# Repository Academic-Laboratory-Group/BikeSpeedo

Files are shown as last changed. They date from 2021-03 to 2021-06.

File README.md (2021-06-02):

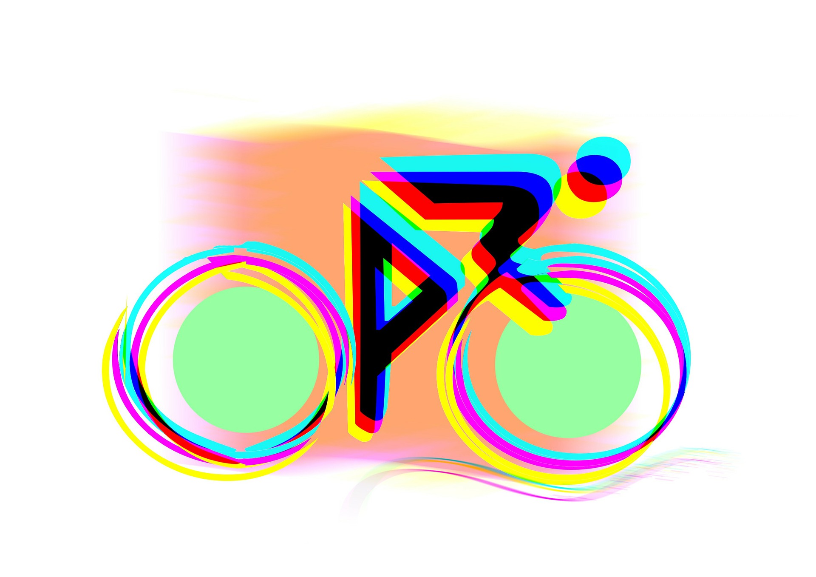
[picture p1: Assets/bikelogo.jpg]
ReadMe


# BikeSpeedo
Bicycle speedometer. Project for Sensors In Embedded Systems, Electronics and Telecommunications, master's studies at University of Science and Technology in Cracow. Classes are led in Polish so description and files from this place will be too, except code and other source files.

## Cel projektu
Celem projektu jest skonstruowanie modułu prędkościomierza rowerowego do płytki Nucleo. Należy zaprojektować płytkę PCB oraz oprogramowanie. Ważną cechą projektu ma być przystępna cena gotowego produktu mimo zainstalowanych w nim udogodnień (wyświetlacz dotykowy, zasilanie bateryjne). Projekt ma być możliwy do użycia w celach edukacyjnych, a więc zaprojektowany tak, żeby dało się łatwo zrozumieć zastosowane w nim rozwiązania.

## Podział obowiązków
Nad częścią hardware-ową główny nadzór będzie sprawował Krzysztof, natomiast nad software-ową Norbert. Oczywiście w projekcie przewidziana jest ciągła współpraca, co powinno być widoczne na koniec w postaci przeplatających się commitów obu członków.

## Założenia projektowe
* Pomiar prędkości przy pomocy czujnika Halla na podstawie liczby obrotów koła.
* Konfiguracja oraz prezentacja wyników na wyświetlaczu dotykowym.
* Urządzenie zasilane z akumulatora (z pełną jego obsługą, czyli ładowarką + monitoringiem stanu naładowania).
* Projekt płytki PCB w celu demonstracji urządzenia.
* Szacowany czas pracy na baterii Li-Ion o pojemności 1300 mAh powinien wynieść około 7.5 godziny.

## Efekt
Effect

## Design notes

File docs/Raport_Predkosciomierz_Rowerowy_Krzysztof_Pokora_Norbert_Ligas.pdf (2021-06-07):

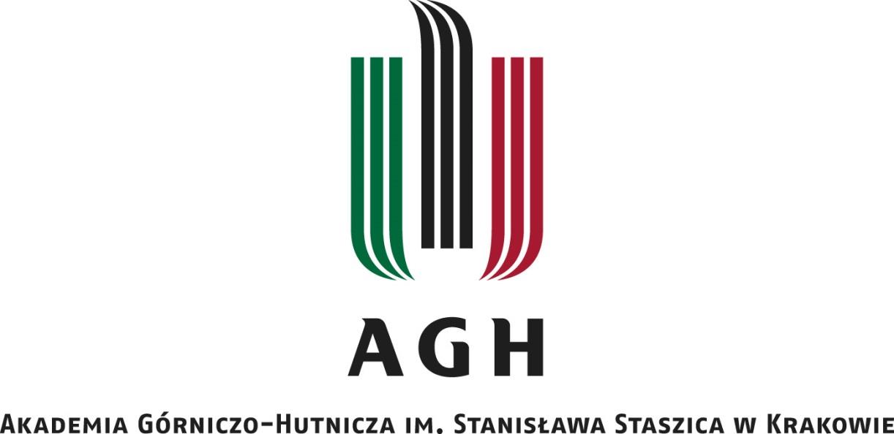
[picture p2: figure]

WYDZIAŁ INFORMATYKI, ELEKTRONIKI I TELEKOMUNIKACJI

KATEDRA ELEKTRONIKI I TELEKOMUNIKACJI

# Prędkościomierz rowerowy

Autorzy: | Krzysztof Pokora i Norbert Ligas
Kierunek studiów: | Elektronika i Telekomunikacja
Typ studiów: | Stacjonarne
Opiekun: | mgr inż. Jan Macheta

Kraków, 2021/2022

## 1. Spis treści

## 1. Cel oraz wstęp

Celem projektu jest skonstruowanie modułu prędkościomierza rowerowego do płytki Nucleo. Należy zaprojektować płytkę PCB oraz oprogramowanie. Ważną cechą projektu ma być przystępna cena gotowego produktu mimo zainstalowanych w nim udogodnień (wyświetlacz dotykowy, zasilanie bateryjne). Projekt ma być możliwy do użycia w celach edukacyjnych, a więc zaprojektowany tak, żeby dało się łatwo zrozumieć zastosowane w nim rozwiązania.
Prędkościomierz rowerowy to niewielkie, ale niezwykle przydatne akcesorium. Urządzenie to jest bardzo popularne w dzisiejszych czasach. Nie jest obowiązkowym wyposażeniem każdego roweru, lecz jest ono dodatkowo montowane urządzenie. Na rynku występuje wiele rodzajów liczników rowerowych. Najbardziej rozbudowane posiadają między innymi: pulsometr, ilość spalonych kalorii, termometr, a nawet sygnalizator dźwiękowy nadający tempo. Przykład takiego licznika został przedstawiony na Rys. 1.1 [11]

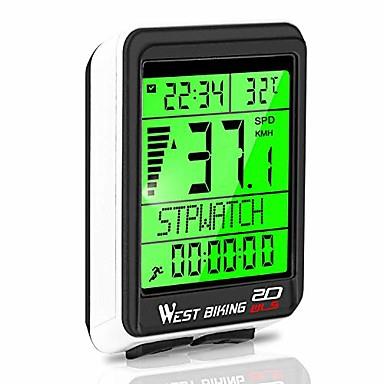
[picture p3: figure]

Rys. 1.1 Licznik rowerowy [10]

Liczniki rowerowe są wykorzystywane głównie podczas treningu kolarskiego, ale również przez każdego człowieka jako dodatkowy gadżet. Oferując wiele funkcji, takich jak mierzenie dystansu, prędkości chwilowej jak i średniej, czy w połączeniu z sensorem mierzenie pulsu, pozwalają właściwie zaplanować swój wysiłek, jak i odpowiednio móc go podsumować celem poznania swoich postępów. Szeroka gama dostępnych modeli, obejmująca zarówno liczniki rowerowe bezprzewodowe jak i przewodowe daje szerokie pole do wyboru urządzenia. Liczniki bezprzewodowe, pozwalają na zminimalizowanie niechcianych elementów których instalacja na rowerze jest konieczna. Transmisja danych pomiędzy czujnikiem, a jednostką centralną odbywa się za pośrednictwem fal radiowych. Tańsze modele wciąż wykorzystują analogową transmisję danych, co może wiązać się z wystąpieniem zakłóceń w pobliżu silnego
pola | magnetycznego. | Cyfrowa | technologia | transmisji | bezprzewodowej | obniża
prawdopodobieństwo wystąpienia zakłóceń, ale licznik wyposażony w taką technologię jest z reguły droższy. Natomiast liczniki przewodowe, jak sama nazwa wskazuje wymagają przewodu do skomunikowania czujnika z jednostką centralną. Dobrze zamontowany przewód zazwyczaj nie przeszkadza w użytkowaniu w warunkach miejskich, jednak w trudnym terenie, można go łatwo uszkodzić. Zaletą liczników przewodowych jest niska cena i brak zakłóceń w transferze impulsów.

## 2. Założenia projektowe

- Pomiar prędkości przy pomocy czujnika Halla na podstawie liczby obrotów koła
- Wykorzystanie | platformy | NUCLEO | STM32F446RE | jako | urządzenia
zarządzającego
- Konfiguracja oraz prezentacja wyników na wyświetlaczu dotykowym
- Urządzenie zasilane z akumulatorka (łącznie z ładowaniem)
- Projekt płytki PCB

## 3. Wstęp teoretyczny

Zasada działania licznika rowerowego polega na zliczaniu czasu pomiędzy impulsami, a następnie znając średnice koła obliczana jest prędkość. Impulsy są wywoływane przez przemieszczanie się obok czujnika elektromagnetycznego zamontowanego na widelcu roweru nadajnika impulsów zainstalowanego na szprychach lub poprzez generowanie impulsów w układzie magnes-kontaktron. Starsze konstrukcje liczników były prostymi urządzeniami mechanicznymi, w których przykręcona do szprychy śruba z kołkiem obracała małe kółko zębate na osi mechanicznego licznika przykręconego do widelca roweru. Aby obliczyć prędkość z jaką porusza się rowerzysta należy znać średnice lub promień koła. Przeważnie, wielkość koła podawana jest w calach, dlatego należy najpierw zamienić jednostki na centymetry według wzoru 1.1. Na przykład koło mające 24 cale posiada średnicę 0,6096 m.

1 cal = 2.54cm = 0.0254m | (1.1)

Następnie znając średnicę koła można obliczyć jego obwód przy pomocy wzoru 1.2.

L = π ∙ d | (1.2)

Gdzie:
d – średnica koła
L – obwód koła

Kolejnym krokiem jest zliczanie czasu pomiędzy impulsami dostarczanego przez czujnik pola magnetycznego. Na jednej ze szprych koła umieszczony jest magnes, natomiast na widelcu roweru czujnik pola. Oba te elementy są umieszczone na tej samej odległości od środka koła. Podczas jazdy magnes obraca się wraz z kołem. Gdy magnes pojawi się w pobliżu czujnika, wysyła on impuls sygnału do układu zarządzającego. W przypadku tego projektu został wykorzystany mikrokontroler STM32F446RE, oraz czujnik Halla. Szczegółowe informacje na ich temat znajdują się w rozdziale 4.
W dalszej części, znając już średnicę oraz czas pomiędzy impulsami można obliczyć średnią prędkość rowerzysty. W tym celu należy skorzystać ze wzoru 1.3.

V =

S t
=
L t | (1.3)

Gdzie:
V – średnia prędkość roweru
L – obwód koła
t – czas pomiędzy impulsami z czujnika pola magnetycznego

Ponadto, skoro znamy już obwód koła oraz impuls w momencie obrotu całego koła, możliwe jest zliczanie kilometrów. Za każdym obrotem koła, do wartości przebytych kilometrów byłaby doliczana wartość obwodu koła.

## 4. Opis elementów

### 4.1. Czujnika pola magnetycznego – czujnik Halla

Czujnik Halla wykorzystuje zjawisko Halla polegające na powstawaniu napięcia w materiale, który przewodzi prąd elektryczny umieszczonym w polu magnetycznym. Najczęściej obszar “aktywny” czujnika to płytka półprzewodnikowa, jak na rysunku 4.1, w której generowane jest napięcie. Prąd o natężeniu I przepływa w kierunku długości płytki od styku IC(+) do IC(-). Pole magnetyczne jest skierowane w osi z, czyli prostopadle do płaszczyzny płytki. Pole to oddziałuje na nośniki prądu (elektrony lub dziury) siłą Lorentza odpychającą je w kierunku krawędzi płytki. Na skutek tego, na krawędziach płytki gromadzi się pewien nadmiar ładunków, po jednej stronie dodatnich, po drugiej ujemnych, a w konsekwencji na stykach VH(+) i VH(-) powstaje napięcie Halla proporcjonalne do gęstości strumienia pola magnetycznego. [1]

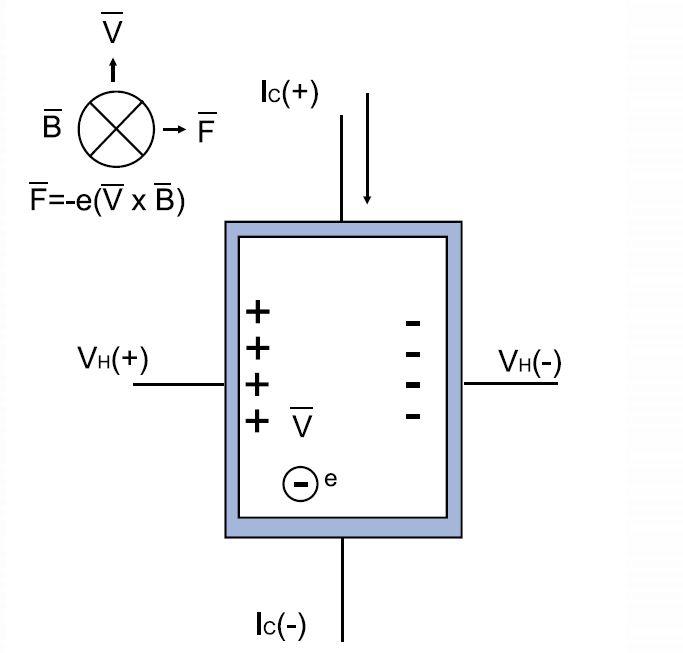
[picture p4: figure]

Rys. 4.1 Generowanie i pomiar napięcia Halla w stałym polu magnetycznym [1]

Generowane napięcie jest zależne od kąta wektora strumienia pola magnetycznego do powierzchni Halla. Jego wartość obliczana jest przy pomocy wzoru 4.1.

VH = γB | ∙ B ∙ sinθ | (4.1)

Gdzie:
VH – napięcie Halla
γB – czułość magnetyczna materiału, z którego wykonany jest czujnik

B – indukcja magnetyczna (gęstość strumienia pola magnetycznego
θ – kąt pomiędzy wektorem strumienia pola magnetycznego, a powierzchnią Halla

Generowane napięcie Halla jest maksymalne, jeżeli wektor strumienia pola magnetycznego jest prostopadły do powierzchni Halla. Wtedy wzór 4.1 można skrócić do wersji 4.2.[1]
VH = γB | ∙ B | (4.2)

Napięcie Halla jest napięciem bardzo niskim, rzędu µV z tego powodu stosuje się dodatkowo wzmacniacze. Do poprawnej pracy czujnika Halla potrzebne jest jeszcze jak było wspomniane wcześniej źródło prądowe. Zapewnia ono przepływ prądu przez płytkę czujnika. W niektórych aplikacjach stosowany jest rezystor obciążający włączany na wyjściu czujnika. W projekcie został wykorzystany czujnik Halla AH49E przedstawiony na rys. 4.2. Jest to moduł z czujnikiem Halla wyposażony w wyjście analogowe oraz cyfrowe. Pracuje z napięciem od 2,3 V do 5,3 V. Czułość wynosi 1,6mV/GS. W projekcie wykorzystywane jest wyjście cyfrowe, gdyż interesuje nas wyłącznie wykrycie pola magnetycznego, a nie jego wartość. [2]

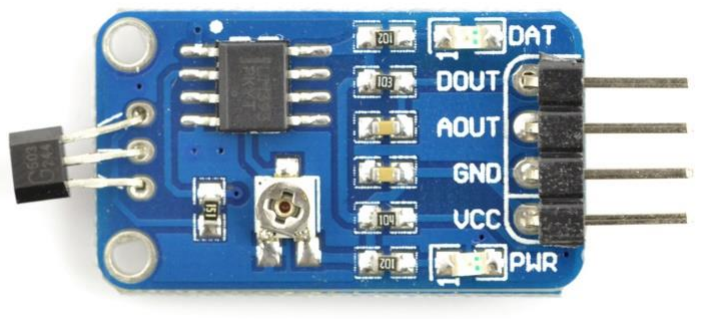
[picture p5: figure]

Rys. 4.2 Czujnik Halla AH49E [2]

Podstawowymi elementami funkcjonalnymi modułu jest AH49E - scalony czujnik efektu Halla oraz LM393 - układ scalony komparatora analogowego (wzmacniacza operacyjnego z otwartą pętlą sprzężenia zwrotnego). Sygnał analogowy doprowadzony z czujnika Halla AH49E jest liniowo proporcjonalny do wartości natężenia pola magnetycznego zmierzonej przez ten czujnik. Kiedy czujnik nie wykrywa pola magnetycznego w swoim zasięgu działania, poziom sygnału na jego wyjściu jest równy połowie wartości napięcia ze źródła zasilania podawanego na wyprowadzenie VCC. Wartość progu wykrywania jest nastawiana za pomocą potencjometru montażowego umieszczonego na płytce modułu czujnika. [2]

### 4.2. Wyświetlacz dotykowy

Elementem odpowiedzialnym za interfejs użytkownika jest wyświetlacz dotykowy przedstawiony na rys. 4.3. Jest to 4 calowy rezystancyjny ekran o rozdzielczości 480 x 320 px. Współpracuje z Arduino oraz Nucleo poprzez interfejs SPI. Napięcie zasilania wymosi 5V. Dodatkowo posiada on przylutowane złącza Arduino, dzięki którym możliwe jest bezpośrednie podłączenie wyświetlacza do płytki, bez użycia dodatkowych przewodów. Na płytce znajduje się również slot kart microSD. [3]

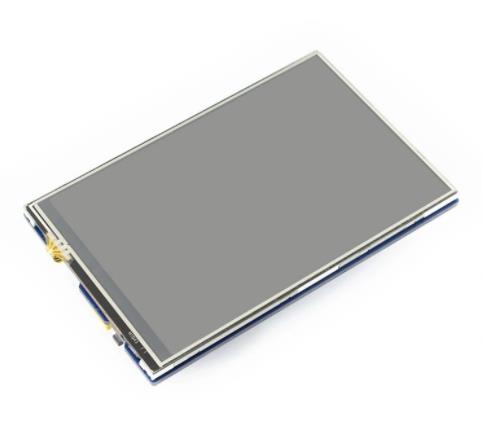
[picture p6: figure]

Rys. 4.3 Wyświetlacz dotykowy [3]

### 4.3. Kontroler zarządzający ładowaniem baterii MCP73833

MCP73833 jest to zaawansowany układ do zarządza baterią firmy Microchip Technology (zaprezentowany na rys.4.4). Jego głównym zadaniem jest ładownie baterii Li-Ion. Służy także do kontrolowania pracy baterii. Na podstawie informacji dostarczonych z termistora o temperaturze baterii, układ dostosowuje prąd ładowania lub przestaje ją ładować w przypadku zbyt wysokiej temperatury. Urządzenie ładuje ogniwa wykorzystując stały prąd oraz napięcie. Posiada możliwość wyboru momentu zakończenia ładowania. Ponadto użytkownik ma do wyboru sposób wstępnego ładowania. Między innymi są to wartości prądu oraz moment, w którym ładowarka ma rozpocząć ładowanie ogniwa. Wartość prądu ustalana jest przy pomocy zewnętrznego rezystora. Stosunek lub procent ustalonego prądu wyznacza wartość wstępnego oraz końcowego ładowania. Napięcie natomiast wybierane jest spośród czterech różnych opcji. Napięcia zawierają się w przedziale od 4.2 V do 4.5 V. Różne napięcia wynikają z nowych wymagań dostarczanych wraz z nowymi wyprodukowanymi bateriami. Wszystkie te operacje są w celu zapewnienia jak największej kompatybilności urządzeń. Urządzenie jest zdolne ładować jedno ogniwową baterię o maksymalnym prądzie 1 A. Dodatkowo układ posiada wiele zabezpieczeń. Między innymi zastosowano zabezpieczenie baterii przed wstecznym rozładowaniem. Układ doskonale sprawdzi się w sytuacjach, gdy ogniwo jest znacząco rozładowane. Wtedy układ dostosowuje parametry tak, aby bardziej nie uszkodzić, a jedynie próbować naładować ponownie baterie. Urządzenie znajduje swoje zastosowanie między innymi w aparaturze przenośnej, transmisji bezprzewodowej czy urządzeniach audio. Napięcie wejściowe układu zawiera się w przedziale od 3.75 V do 6 V. Układ dostępny jest w obudowie MSOP-10. [4]

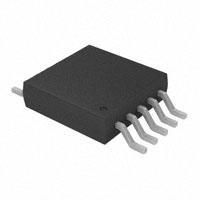
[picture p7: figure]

Rys. 4.4 MCP73833 – Kontroler zarządzania baterią Li-Ion [7]

### 4.4. Przetwornica TPS61202

Przetwornica przedstawiona na rys. 4.5 zapewnia zasilanie dla urządzeń zasilanych jedno, dwu lub trzy ogniwowymi bateriami. Prąd wyjściowy jest zależny od stosunku napięcia wejściowego do wyjściowego. Urządzenie generuje prąd wyjściowy do 600 mA na wyjściu przy napięciu wyjściowym 5 V oraz wejściowym powyżej 3 V lub prąd wyjściowy do 300mA przy napięciu wyjściowym 3.3V oraz wejściowym powyżej 2.4V, przy wykorzystaniu jednoogniwowego akumulatora Li-Ion lub Li-Polymer. Zakres napięć wejściowych zawiera się w przedziale od 0.3V do 5.5V. Przetwornica step-up oparta jest na stałej kontroli częstotliwości, modulacji szerokości impulsu (PWM) za pomocą prostowania synchronicznego w celu uzyskania maksymalnej wydajności. Przy niskich prądach obciążenia konwerter przechodzi w tryb oszczędzania energii, aby utrzymać wysoką sprawność w szerokim zakresie prądu obciążenia. Tryb oszczędzania energii można wyłączyć, zmuszając konwerter do działania ze stałą częstotliwością przełączania. Średni prąd wejściowy jest ograniczony do maksymalnej

wartości 1500 mA. Napięcie wyjściowe jest programowane przez zewnętrzny dzielnik. Konwerter można wyłączyć, aby zminimalizować drenaż baterii. Podczas wyłączania obciążenie jest całkowicie odłączane od akumulatora. [5]

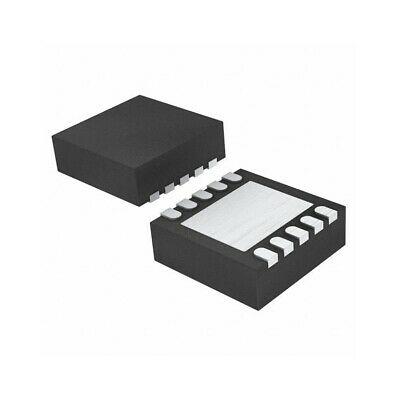
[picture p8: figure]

Rys. 4.5 Przetwornica TPS61202 [8]

### 4.5. Mikrokontroler NUCLEO STM32F446RE

Moduł z 32-bitowym mikrokontrolerem przedstawiony na rys. 4.6 jest wyposażonym w rdzeń ARM Cortex M4 o częstotliwości taktowania 180 MHz, pamięci Flash 512 kB, pamięci SRAM128 kB. Nucleo jest kompatybilny z platformą mbed, posiada złącza umożliwiające podłączenie nakładek Arduino tzw. Arduino Shield. Moduły są kompatybilne z nakładkami Arduino oraz systemem kompilatora on-line mbed.org. Nucleo współpracuje z większością popularnych platform programistycznych w tym Keil, IAR oraz środowiskami opartymi na kompilatorze GCC. [6]
Interfejsy komunikacyjne:
- 4x SPI,
- 2x I2C,
- 4x USART,
- 2x UART,
- 2x CAN,
- USB OTG,
Inne podzespoły:
- 3x przetwornik ADC: 12 bitów, 16 kanałów
- Przetwornik DAC: 12 bitów, 2 kanały

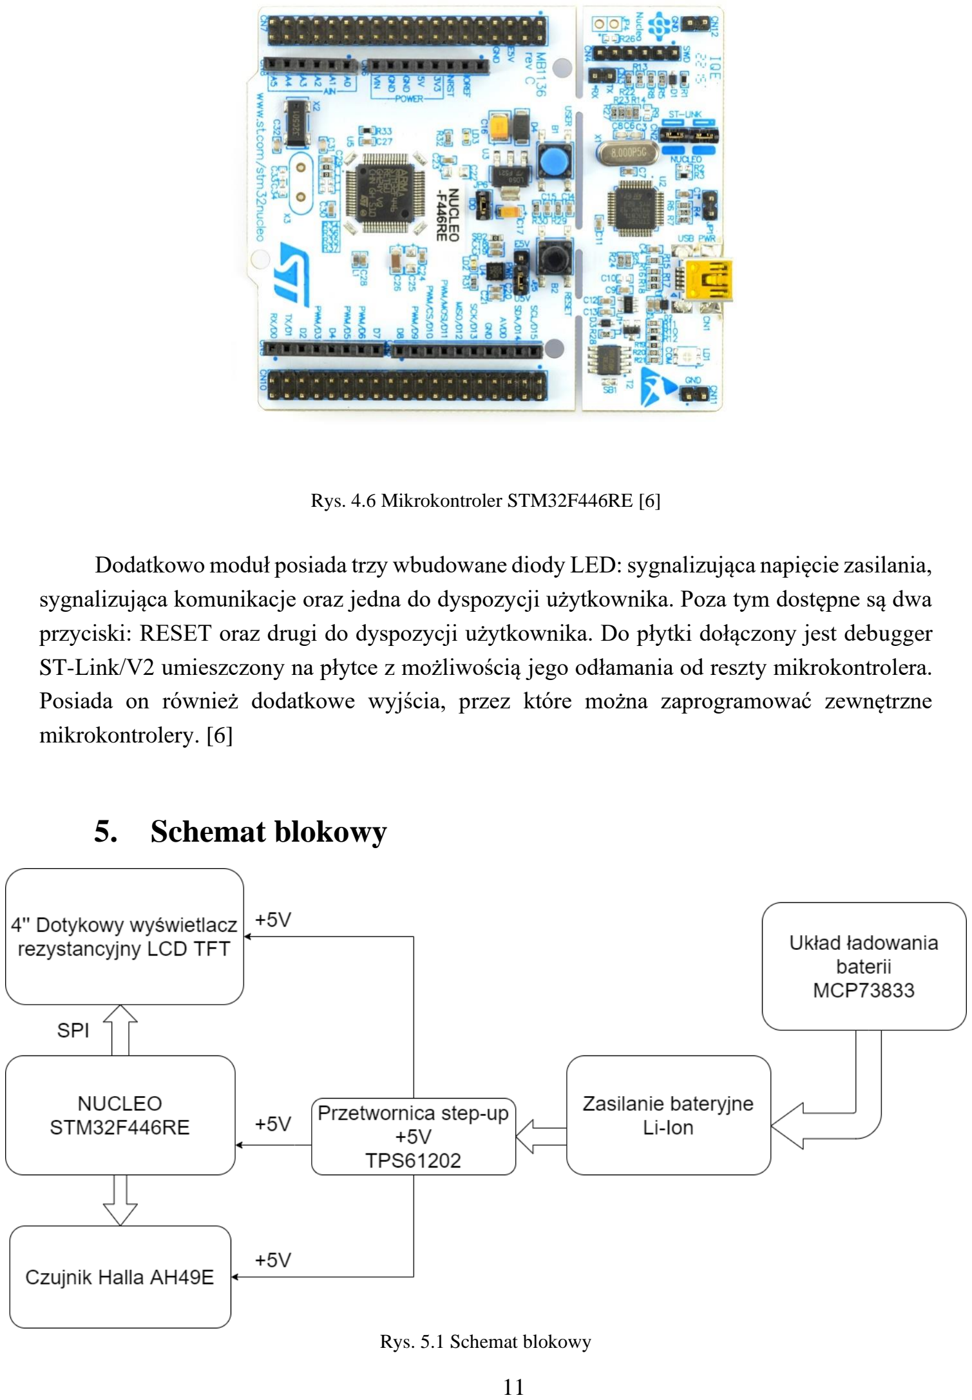
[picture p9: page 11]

Rys. 4.6 Mikrokontroler STM32F446RE [6]

Dodatkowo moduł posiada trzy wbudowane diody LED: sygnalizująca napięcie zasilania, sygnalizująca komunikacje oraz jedna do dyspozycji użytkownika. Poza tym dostępne są dwa przyciski: RESET oraz drugi do dyspozycji użytkownika. Do płytki dołączony jest debugger ST-Link/V2 umieszczony na płytce z możliwością jego odłamania od reszty mikrokontrolera. Posiada on również dodatkowe wyjścia, przez które można zaprogramować zewnętrzne mikrokontrolery. [6]

## 5. Schemat blokowy

Rys. 5.1 Schemat blokowy

Na rys 3.10 został przedstawiony schemat blokowy urządzenia. Prędkościomierz można podzielić na 4 główne bloki: Mikrokontroler, Wyświetlacz, Czujnik oraz Zasilanie. Wyświetlacz komunikuje się z mikrokontrolerem przy pomocy interfejsu szeregowego SPI, natomiast czujnik Halla przy pomocy portu GPIO, gdyż sygnał dostarczany z czujnika jest sygnałem cyfrowym zero jedynkowym. Urządzenie nie posiada żadnych przycisków służących do obsługi urządzenia, ponieważ został zastosowany wyświetlacz dotykowy, który łączy funkcje interfejsu oraz wyświetlania. Jedyny przełącznik użyty w projekcie służy do włączania oraz wyłączania urządzenia. Wszystkie układy zasilane są napięciem 3.3V lub 5V, poza wyświetlaczem, który posiada wbudowany stabilizator 3.3V z tego powodu potrzebne jest zastosowanie napięcia zasilania 5V. Z racji, że napięcie na baterii znajduje się w przedziale od 2.6V do 4.1V w zależności od naładowania potrzebne jest zastosowanie przetwornicy step-up 5V. Przetwarza ona napięcie baterii do poziomu 5V. Dodatkowo urządzenie posiada wbudowany układ służący do ładowania oraz kontroli pracy baterii. Więcej informacji na ten temat w rozdziale 6.

## 6. Projekt układu

### 6.1. Układ ładowania ogniwa oraz stabilizacji napięcia

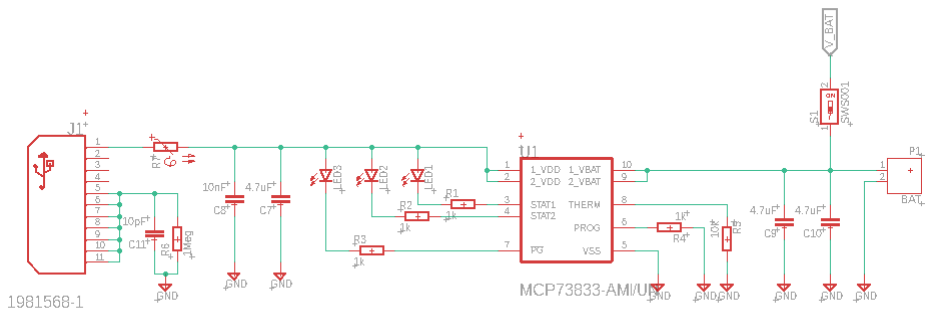
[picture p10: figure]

Rys. 6.1 Schemat układu ładowania ogniwa

W pierwszej kolejności został zaprojektowany układ służący ładowaniu oraz kontroli pracy baterii. Schemat układu został przedstawiony na rys. 6.1. W projekcie został wykorzystany układ scalony MCP73833. Został on skonfigurowany do ładowania ogniwa prądem 1 A poprzez dobranie odpowiedniego rezystora R4. Wartość jego została obliczona według poniższego wzoru podanego w dokumentacji układu.

### IREG =

1000V

RPROG

(6.1)

gdzie:
IREG – prąd ładowania ogniwa [A] RPROG – wartość rezystora R9 [kΩ]

Napięcie wejściowe układu podawane jest za pośrednictwem złącza micro USB. Powodem zastosowania takiej wersji złącza jest fakt, że jest ono bardzo popularne oraz każdy użytkownik tego urządzenia z pewnością posiada kabel z tym rodzajem złącza. Dodatkowo zaletą jest to, że złącze pracuje przy napięciu o wartości 5 V, natomiast układ MCP73833 przyjmuje napięciu w zakresie do 6 V. W celu filtracji napięcia wejściowego oraz wyjściowego zostały zastosowane kondensatory. Ponadto układ został wyposażony w złącze, do podłączenia baterii. Informacja o stanie naładowania baterii jest przekazywana za pomocą 3 diod podłączonych do układu. Dioda LED1 sygnalizuje zakończenie procesu ładowania ogniwa. Dioda LED2 informuje o obecności zasilania, tzn. o obecności napięcia na złączu USB. Natomiast dioda LED3 służy do informowania użytkownika o momencie ładowania ogniwa. Jeśli dioda się zaświeci oznacz, że bateria jest w danym momencie ładowana. Urządzenie jest załączane oraz wyłączane przy mocy przełącznika SWS001.
Dodatkowo na wejściu układu został zastosowany bezpiecznik polimerowy. Jest to element zabezpieczający układ elektroniczny przed uszkodzeniem, które mogłoby nastąpić w związku z przepływem zbyt dużego prądu (np. w wypadku zwarcia). Od innych bezpieczników odróżnia go przede wszystkim możliwość wielokrotnego użycia. Element ten jest tak właściwie termistorem, czyli rodzajem rezystora, który zmienia swój opór w zależności od tego jaka panuje temperatura. Zabezpieczenie to jest projektowane tak, aby po przekroczeniu maksymalnego prądu zaczął się on mocno nagrzewać. Wzrost temperatury sprawia, że opór elementu znacznie wzrasta co prowadzi do przerwania obwodu.
W dalszej części, chcąc zasilić wszystkie podzespoły należy ustabilizować napięcie do poziomu 5 V (schemat przedstawiony na rys. 6.2). W tym celu został zaprojektowany układ przetwornicy step-up na układzie TPS61202. Posiada on maksymalny prąd wyjściowy o wartości do 600mA, który jest wystarczający, aby zapewnić prawidłową pracę wszystkich układów. Na rys. 6.3 została również przedstawiona charakterystyka układu, prądu wyjściowego w zależności od napięcia wejściowego.

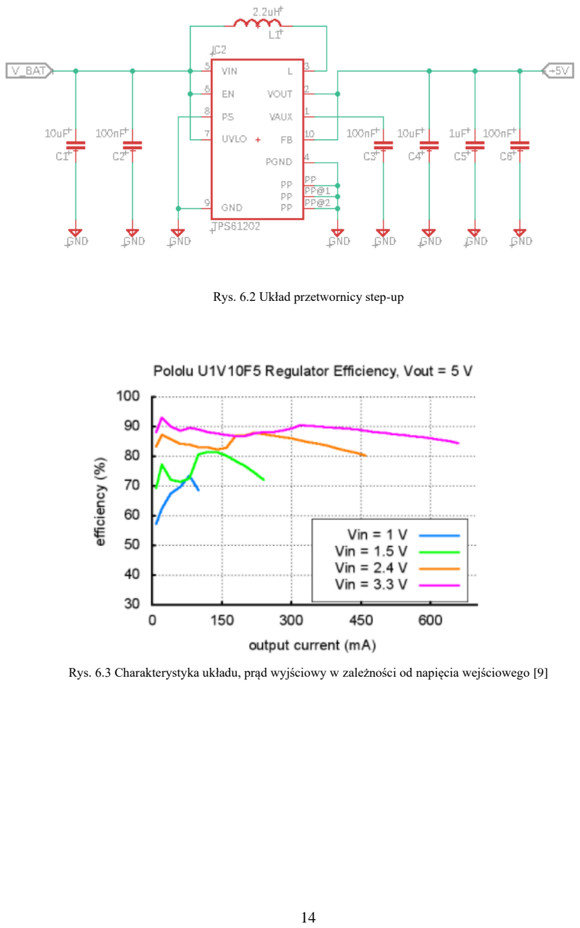
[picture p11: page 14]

Rys. 6.2 Układ przetwornicy step-up

Rys. 6.3 Charakterystyka układu, prąd wyjściowy w zależności od napięcia wejściowego [9]

### 6.2. Projekt PCB

Płytka PCB została wykonana z elementów SMD, czyli powierzchniowych oraz THT czyli przewlekanych. W celu poprawy widoczności oraz nie zaciemniania elementów, zdjęcie płytki zostało wykonane bez wylanej masy (rys. 6.4).
Kondensatory blokujące zostały ułożone jak najbliżej układów zasilanych. W układach cyfrowych, pobór prądu może zmieniać się bardzo szybko , nawet o kilka rzędów wielkości. Największy pobór prądu występuje podczas zmiany poziomów napięć z 0 do 3.3 V lub 5 V. Takimi urządzeniami są szczególnie układy wykonane w technologii CMOS. Taka szybka zmiana poboru prądu może doprowadzić do dużej niestabilności napięcia zasilania, a w konsekwencji niepoprawnej pracy układów. W tym celu stosuje się kondensatory blokujące.

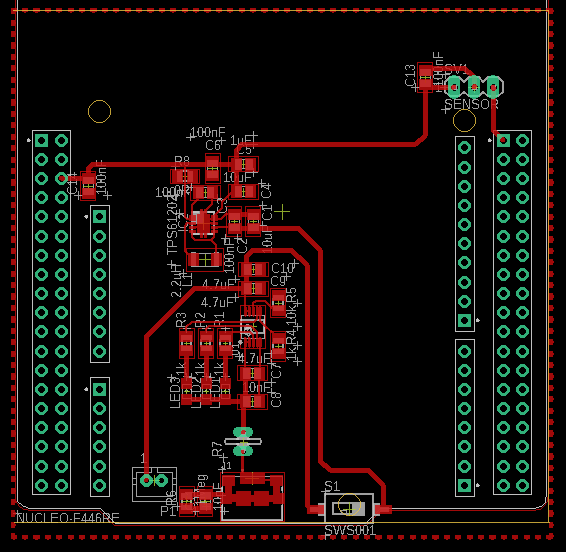
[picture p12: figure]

Rys. 6.4 Projekt płytki PCB bez wylanej masy

## 7. Instrukcja obsługi prędkościomierza rowerowego

Licznik rowerowy jest to bardzo proste urządzenie, służące do obliczania prędkości rowerzysty. Z tego powodu interfejs użytkownika został zaprojektowany tak, aby w łatwy i szybki sposób móc rozpocząć w aktywny sposób korzystać z urządzenia.. Od momentu włączenia urządzenia wystarczy wykonać 3 kroki, aby móc cieszyć się z informacji jak szybko można jechać na rowerze.

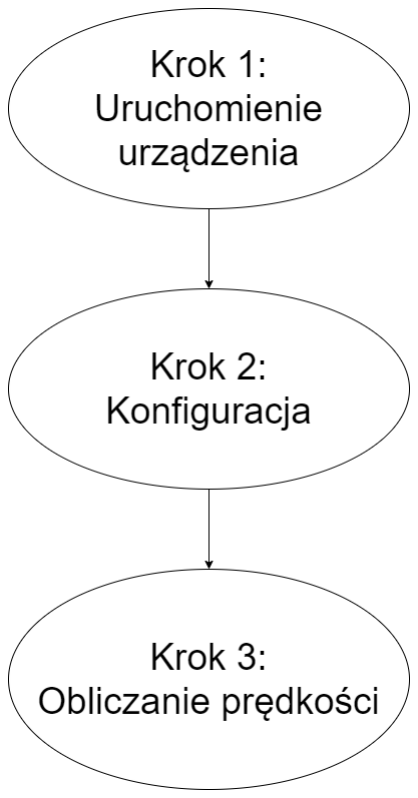
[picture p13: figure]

Rys. 7.1 Graf postępowania przy konfiguracji urządzenia

Na rys. 7.1 został przedstawiony graf postępowania od włączenia do wyświetlania informacji o prędkości. Po włączeniu urządzenia w pierwszej kolejności należy najpierw skonfigurować pracę urządzenia. W tym celu należy wybrać opcje „SETUP”. Jest ona potrzebna, ponieważ rower rowerowi nie równy i posiadają różne rozmiary kół. Oznacza to, że w konfiguracji należy podać rozmiar koła w calach. W kolejnym kroku należy zatwierdzić zmiany oraz wrócić do głównego menu przyciskiem „ENTER” i wybrać obliczanie prędkości przyciskiem „VELOCITY”. Jeśli byśmy wybrali opcje „RETURN” zmiany by nie zostały zapisane. Po wejściu w tą funkcje, na górze będzie wyświetlana prędkość w formie liczbowej, natomiast pod nią jest rysowany wykres tej prędkości w zależności od czasu. Wartość prędkości jest obliczana co sekundę. Zostało również zastosowane zabezpieczenie. Jeśli wybierze się opcje „VELOCITY” bez wcześniejszej konfiguracji to urządzenie poprosi najpierw o przejście do opcji „SETUP”. Również po wyjściu z opcji „VELOCITY” po wcześniejszej konfiguracji wykres jest resetowany.

## 8. Oprogramowanie

W projekcie został wykorzystany mikrokontroler, dlatego w tym celu zostało stworzone
oprogramowanie, | na | repozytorium: | https://github.com/Academic-Laboratory-
Group/BikeSpeedo (https://github.com/Academic-Laboratory-Group/BikeSpeedo) . Aby dokonać połączenia miedzy mikrokontrolerem, a wyświetlaczem została wykorzystana biblioteka dostarczona od producenta. Wyświetlacz komunikuje się poprzez interfejs szeregowy SPI.
SPI jest to szeregowy interfejs służący najczęściej do komunikacji mikrokontrolera z urządzeniami peryferyjnymi. Jest jednym z 3 najpopularniejszych interfejsów komunikacyjnych. W przypadku SPI jeden układ, przeważnie jest to mikrokontroler, jest układem nadzorującym tzw. Master, a drugi, w przypadku tego projektu wyświetlacz, podwładnym tzw. Slave. Transmisja danych odbywa się w jednym lub dwóch kierunkach jednocześnie. Komunikacja pomiędzy urządzeniami odbywa się za pomocą 3 linii. Czwarta linia służy do wyboru urządzenia, z którym chcemy się skomunikować. Schemat połączenia urządzeń został zaprezentowany na rys. 3.11.

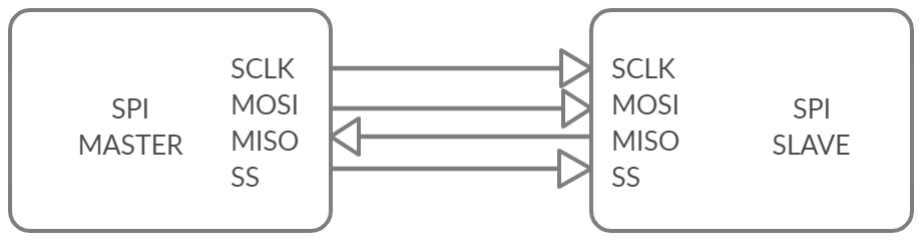
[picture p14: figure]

Rys. 3.11 Schemat połączenia dwóch urządzeń przy pomocy interfejsu szeregowego SPI

Kolejno przedstawione porty na rys 3.11 oznaczają:
- SCLK (Serial Clock) – linia zegara
- MOSI (Master Output Slave Input) – dane wysyłane z mastera do slave
- MISO (Master Input Slave Output) – dane wysyłane z slave do mastera
- SS (Slave Select) – linia wyboru urządzenia

Zaletą korzystania z interfejsu SPI jest to, że wraz z danymi przesyłany jest zegar. Dzięki niemu, możliwe jest uzyskanie szybkich prędkości transmisji. Ponadto komunikacja odbywa się synchronicznie. W celu rozpoczęcia transmisji należy wpierw ustawić stan niski na pinie SS. Od tego momentu urządzenie Slave uruchamia się i następuje możliwość komunikacji z nim. Tylko urządzenie nadzorujące jest w stanie rozpocząć komunikację. To ono może jedynie generować sygnał zegarowy.

Interfejs szeregowy SPI zbudowany jest z 8 synchronicznych przerzutników D tworząc
razem | rejestr | przesuwny. | Wszystkie | przerzutniki | posiadają | ten | sam | zegar.
W momencie wystąpienia zbocza zegara, bit znajdujący się w pierwszym przerzutniku jest przesyłany do drugiego, natomiast z drugiego do trzeciego itd. Sygnał wejściowy jest podawany na wejście pierwszego przerzutnika. Wyjście natomiast ostatniego przerzutnika jest wyjściem z całego rejestru. Oba urządzenia musza posiadać taki mechanizm w celu komunikacji. Ważnym aspektem tego mechanizmu jest fakt, aby urządzenie podwładne mogło wysłać dane, urządzenie nadzorujące musi mu wpierw coś wysłać. W przeciwnym wypadku nie ma możliwości otrzymania danych.
Za pośrednictwem tego interfejsu występuje możliwość komunikacji z wieloma podwładnymi. Do tego służy linia SS. Niestety każde nowe urządzenie należy podłączyć do nowego pinu SS. Do jednego urządzenia peryferyjnego przypada jeden pin SS w mikrokontrolerze. Rys. 3.12 obrazuje schemat podłączenia w przypadku korzystania z wielu urządzeń.

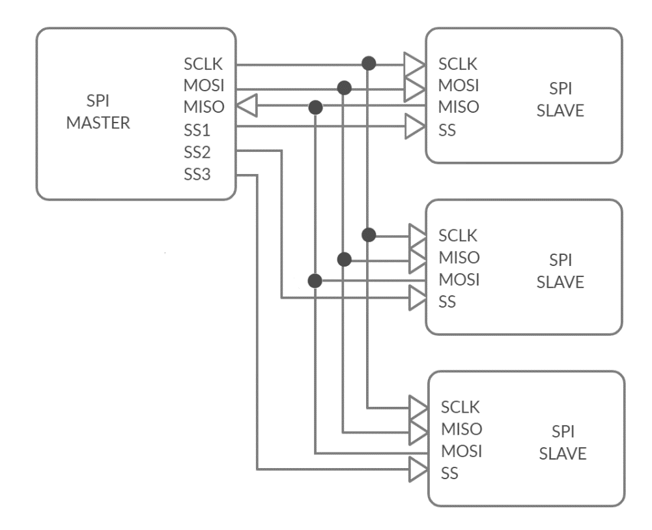
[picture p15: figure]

Rys. 3.12 Schemat połączenia więcej niż jednego urządzenia do tego samego interfejsu SPI

Oprócz interfejsu szeregowego SPI w projekcie zostały wykorzystane liczniki. Pierwszy z nich został wykorzystany do odmierzania czasu po którym ma zostać wykonywany pomiar prędkości. W tym celu została wykorzystana funkcja licznika, a w zasadzie przerwanie od licznika. Licznik został skonfigurowany do pracy ciągłej, tzn. po odliczeniu do zadanej wartości, układ zaczyna liczyć od początku automatycznie wystawiając jedynie przerwanie po odliczeniu do wartości zdanej. Drugi zaś licznik został wykorzystany do odliczania czasu pomiędzy impulsami sygnału dostarczanymi od czujnika Halla. Gdy na wejściu licznika pojawi się przerwanie od czujnika, wartość licznika jest odczytywana i przekazywana do obliczania prędkości oraz w tej samej chwili wartość licznika jest zerowana i następuje wystartowanie licznika od nowa.

## 9. Czas pracy urządzenia na zasilaniu bateryjnym

Zasilanie bateryjne jest to rozwiązanie stosowane coraz częściej. Niestety czas pracy jest ograniczony przez prąd jaki jest pobierany przez urządzenia oraz pojemność wbudowanej baterii. Aby obliczyć maksymalny czas pracy urządzenie na tej baterii należy znać jeszcze pobór prądu każdego z urządzeń. Zestawienie maksymalnego pobieranego prądu przez urządzenia zostało przedstawione w tab. 9.1.

Element elektroniczny | Pobierany prąd [mA]
Układ ładowania MCP73833 | 0.05
Mikrokontroler STM32F446RE | 30
Wyświetlacz 4” | 140
Czujnika Halla AH49E | 3.5
Przetwornica Step-Up | 1
SUMA | 174.55

Tab. 9.1 Maksymalny prąd pobierany przez układy

W następnej kolejności należy skorzystać ze wzoru 9.1:

Czas pracy baterii =

pojemność baterii
prąd obciążenia

(9.1)

Wynika z niego, że minimalny czas ciągłej pracy na zasilaniu bateryjnym przy zastosowaniu baterii o pojemności 1300mAh wynosi około 7.5 godziny. Jest to oczywiście wartość orientacyjna.

## 10. Kosztorys

Element elektroniczny | Liczba elementów | Koszt całkowity [zł]
NUCLEO STM32F446RE | 1 | 72
Wyświetlacz dotykowy 4” | 1 | 104
Czujnik Halla AH49E | 1 | 12
Złącze baterii JST-PH-2-THM_RA | 1 | 0,68
Dioda LED zielona | 1 | 0.25
Dioda LED żółta | 1 | 0.72
Dioda LED czerwona | 1 | 0.36
Kondensator | 12 | 2.5
Cewka | 1 | 3
Rezystor | 7 | 0.5
Złącze gold pin – 3 piny | 1 | 0.12
Przełącznik suwakowy | 1 | 0.9
Micro USB | 1 | 1,35
Bezpiecznik polimerowy | 1 | 4.5
| | SUMA: 202,88 + koszty produkcji płytki

Tab. 10.1 Kosztorys

## 11. Wnioski

Urządzenia takie jak prędkościomierz rowerowy różnią się pod względem ceny jak również możliwości jakie oferują. Pozwalają między innymi liczyć spalone kalorie, obliczać aktualną temperaturę otoczenia czy też mierzyć ciśnienie oraz puls. Jednak cechą wspólna tych urządzeń jest zasilanie bateryjne, wyświetlacz do prezentacji wyników oraz liczenie prędkości co jest podstawową własnością tego urządzenia. Ogólna zasada działania tego typu aparatury jest taka sama. Składają się z czujnika pola magnetycznego, układu zarządzającego, np. mikrokontroler, wyświetlacza oraz źródło pola, np. magnes. W kolejnym etapie zostały przedstawione główne układy elektroniczne użyte w projekcie oraz ich krótka charakterystyka. W trzecim etapie został stworzony schemat blokowy ilustrujący komunikację między układami, sposób prowadzenia zasilania, a przede wszystkim budowę urządzenia. Następnie została dokonana charakterystyka interfejsu po przez który odbywa się komunikacja oraz w jaki sposób zostały wykorzystane zasoby mikrokontrolera. W kolejnej części zostały przedstawione schematy elektryczne oraz dokładne wyjaśnienie sposobu podłączenia oraz celu zastosowania poszczególnych układów. Ostatnim etapem było przedstawienie instrukcji obsługi danego urządzenia oraz kosztorys. Zostały wykonane stosowne wyliczenia dotyczące czasu pracy urządzenia na zasilaniu bateryjnym. Do uruchomienia tego urządzenia zostało napisane dedykowane oprogramowanie. W tej części zostały też opisane najważniejsze problemy z jakimi można się spotkać pisząc kod. Projekt ten można oczywiście bardziej rozwinąć. Między innymi można wprowadzić komunikację urządzenia z komputerem poprzez złącze USB i interfejs USART.

## 12. Bibliografia

1. https://elektronikab2b.pl/technika/33922-czujniki-halla-pomiary-pola-magnetycznegoi-detekcja-polozenia-obiektow
2. https://botland.com.pl/czujniki-pradu/4494-czujnik-halla-ah49e-modul-waveshare-9522.html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
3. https://botland.com.pl/wyswietlacze-lcd-tft-i-ips/10757-ekran-dotykowyrezystancyjny-lcd-tft-4-480x320px-spi-dla-arduino-waveshare-13587.html
4. https://www.tme.eu/Document/00199be6c30361447b781e2dcbb77bbb/mcp73833_4.p df
5. https://www.ti.com/lit/ds/symlink/tps61200.pdf?ts=1622481290644&ref_url=https%2 53A%252F%252Fwww.ti.com%252Fpower-management%252Fnon-isolated-dc-dcswitching-regulators%252Fstep-up-boost%252Fboost-converters-integratedswitch%252Fproducts.html
6. https://botland.com.pl/stm32-nucleo/4905-stm32-nucleo-f446re-stm32f446re-armcortex-m4.html
7. https://cdn.sos.sk/productdata/70/99/32393cd8/mcp73833-ami-un-1.jpg
8. https://i.ebayimg.com/images/g/4AIAAOSwMIVdvHCJ/s-l400.jpg
9. https://botland.com.pl/przetwornice-step-up/1893-u1v11f5-przetwornica-step-up-5v-12a-pololu-2562.html
10. https://ae01.alicdn.com/kf/Hdb4a5beab6224b548ce84f054ebbe1aaL/WEST-BIKING-LED-wodoodporny-komputer-rowerowy-bezprzewodowy-5-j-zyk-kolarstwo-rowerprzebieg-stoper-pr-d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
11. https://pl.wikipedia.org/wiki/Licznik_rowerowy

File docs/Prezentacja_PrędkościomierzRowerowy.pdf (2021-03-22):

# Prędkościomierz rowerowy

Pokora Krzysztof (296507)
Ligas Norbert (296493)
II stopień Elektronika i Telekomunikacja Grupa 17:50

# Cel

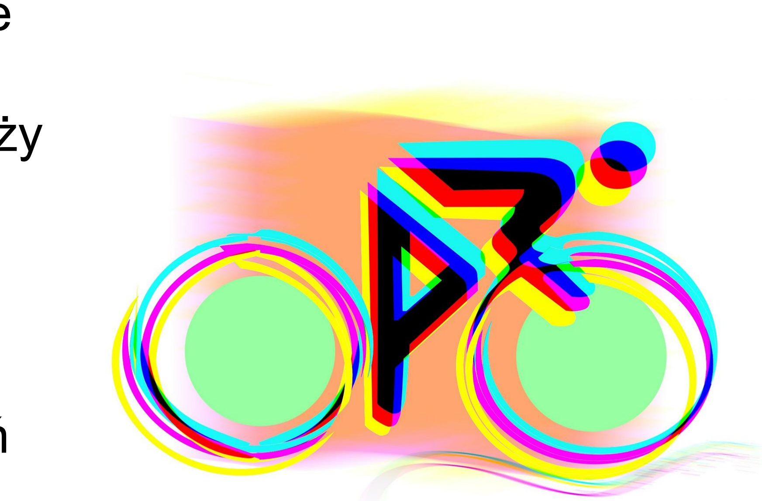
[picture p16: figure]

Celem projektu jest skonstruowanie modułu prędkościomierza
rowerowego do płytki Nucleo. Należy zaprojektować płytkę PCB oraz oprogramowanie. Ważną cechą projektu ma być przystępna cena gotowego produktu mimo
zainstalowanych w nim udogodnień (wyświetlacz dotykowy, zasilanie bateryjne). Projekt ma być możliwy do użycia w celach edukacyjnych, a więc zaprojektowany tak, żeby dało się łatwo zrozumieć zastosowane w nim rozwiązania.

# Podział pracy

Projekt będzie wykonywany

stronie na GitHub. (https://github.com/Academic-Laboratory-Group/BikeSpeedo)

wspólnie na założonej przez grupę (https://github.com/Academic-Laboratory-Group)

Nad częścią hardware-ową główny

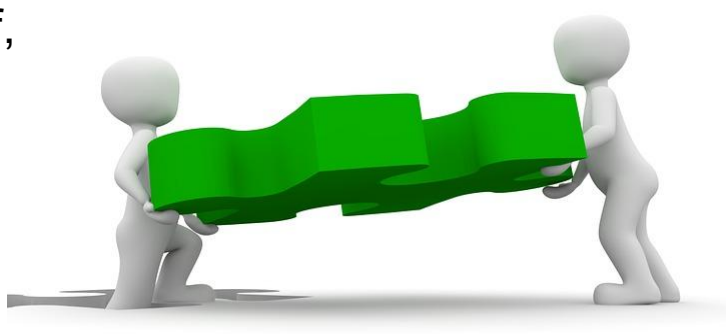
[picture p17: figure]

nadzór będzie sprawował Krzysztof, natomiast nad software-ową Norbert. Oczywiście w projekcie przewidziana jest ciągła
współpraca, co powinno być widoczne na koniec w postaci przeplatających się commitów obu członków.

# Założenia projektowe

» Pomiar prędkości przy pomocy czujnika Halla na podstawie liczby obrotów koła
» Konfiguracja oraz prezentacja wyników na wyświetlaczu dotykowym
» Urządzenie zasilane z akumulatora (z pełną jego obsługą, czyli ładowarką + monitoringiem stanu naładowania)
» Projekt płytki PCB w celu demonstracji urządzenia

# Schemat blokowy

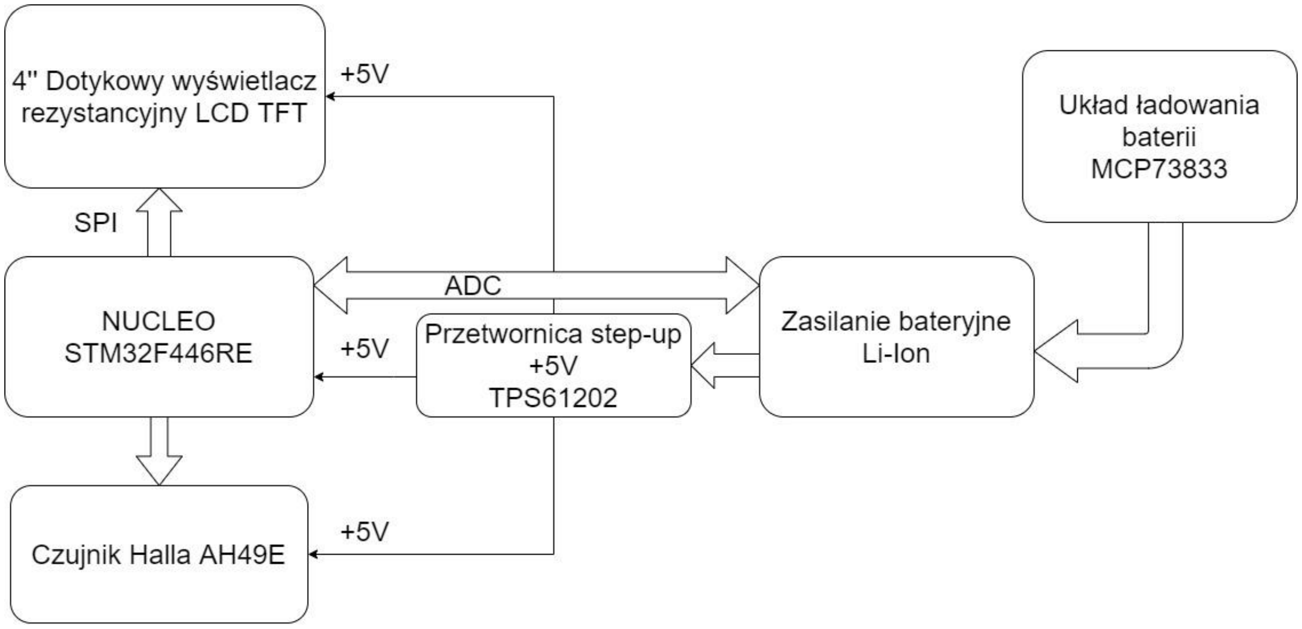
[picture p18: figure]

# Czas pracy na zasilaniu bateryjnym

Element elektroniczny | Pobór prądu
NUCLEO - STM32F446RE | 30mA
Wyświetlacz 4’’ | 140mA
Czujnik Halla AH49E | 3.5mA
Przetwornica step-up | 1mA
| SUMA: 174.5mA

Biorąc pod uwagę baterię o pojemności 1300 mAh, czas pracy będzie wynosił 7.5h.

# Czujnik Halla AH49E

» | posiada wyjście analogowe oraz cyfrowe
» | napięcie zasilania: 2.3V - 5.3V
» | umożliwia detekcję pola magnetycznego
» | czułość: 1.6mV/GS
» | sygnał analogowy jest liniowo
proporcjonalny do wartości natężenia pola magnetycznego zmierzonej przez ten czujnik
» | w zerowym polu magnetycznym wartość
wyjściowa jest równa połowie wartości napięcia ze źródła zasilania podawanego na wyprowadzenie VCC
» | Wartość progu wykrywania jest nastawiana
za pomocą potencjometru montażowego umieszczonego na płytce modułu czujnika

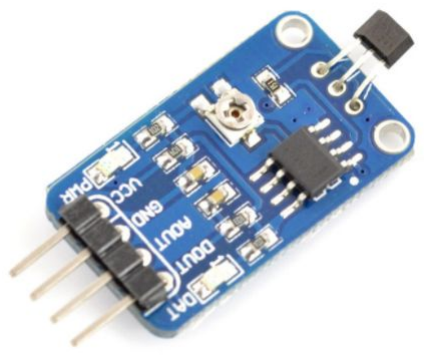
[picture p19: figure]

# Wyświetlacz

» | Rezystancyjny ekran dotykowy LCD TFT, 4",
| rozdzielczość: 480 x 320 px
» | Gniazdo microSD pozwala na na przechowywanie
| obrazów i wyświetlanie ich na ekranie
» | Komunikacja poprzez interfejs SPI
» | Kolor: RGB, 65K
» | Proporcje: 8:5
» | Napięcie zasilania: 3,3 V / 5 V

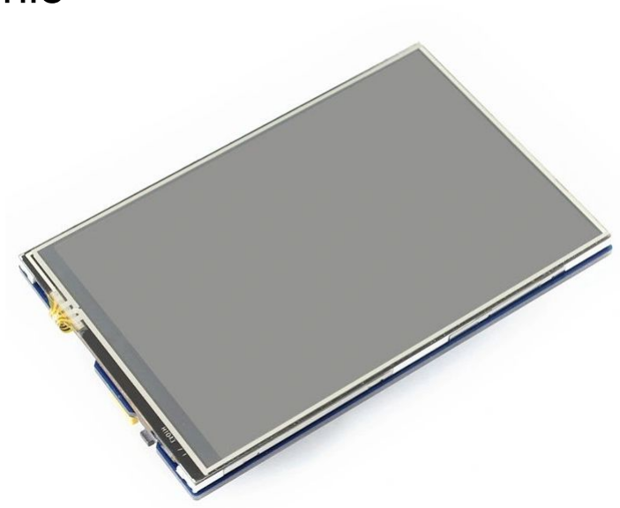
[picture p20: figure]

# Układ ładowania

» | służy do ładowania baterii Li-Ion
» | kontrola pracy baterii oraz dostosowywanie wartości
| prądu na podstawie informacji dostarczonych z termistora
» | stałoprądowe oraz stałonapięciowe ładowanie baterii
» | wartość prądu ładowanie ustalany przy pomocy
| zewnętrznego rezystora (max 1A)
» | napięcie wejściowe: 3.75V - 6V
» | zabezpieczenie przed wstecznym
| rozładowaniem

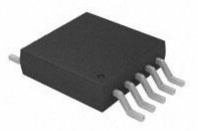
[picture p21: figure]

# Jak obliczyć prędkość?

Aby obliczyć predkość roweru należy znać średnice lub promień koła, a następnie obliczyć jego obwód według wzoru:
L = pi*d lub L = 2*pi*r [m]

Następnie należy liczyć czas pomiędzy impulsami otrzymywanymi od czujnika Halla. Oznaczymy go jako t [s].

Znając czas oraz obwód koła obliczamy prędkość ze wzoru:
V = L/t [m/s]

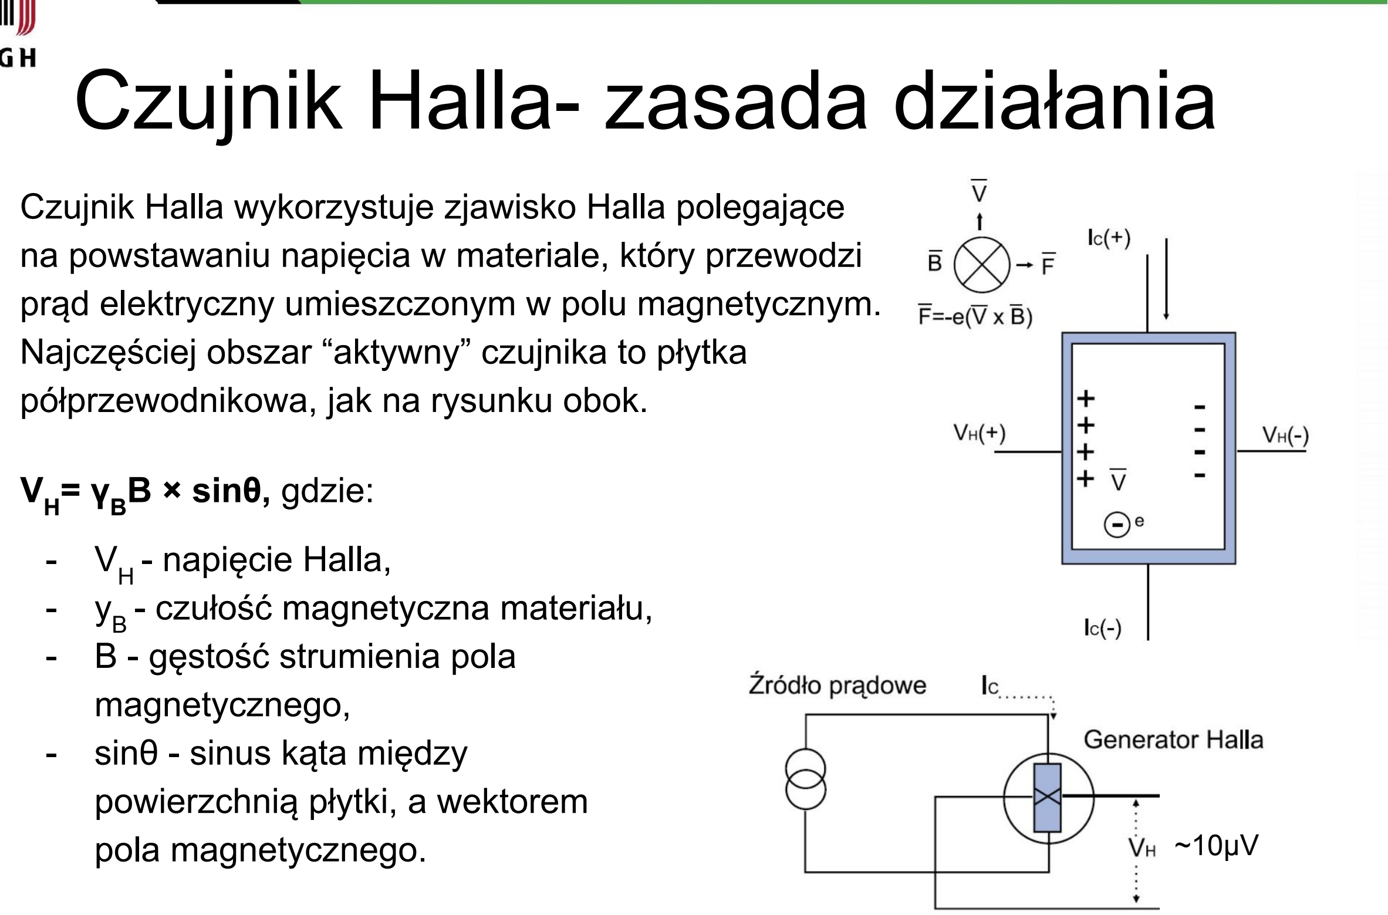
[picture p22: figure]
Czujnik Halla- zasada działania; półprzewodnikowa, jak na rysunku obok.; B × sinθ,; gdzie:; - VH - napięcie Halla, - yB - czułość magnetyczna materiału, - B - gęstość strumienia pola magnetycznego, - sinθ - sinus kąta między powierzchnią płytki, a wektorem; pola magnetycznego.

Czujnik Halla wykorzystuje zjawisko Halla polegające na powstawaniu napięcia w materiale, który przewodzi prąd elektryczny umieszczonym w polu magnetycznym. Najczęściej obszar “aktywny” czujnika to płytka

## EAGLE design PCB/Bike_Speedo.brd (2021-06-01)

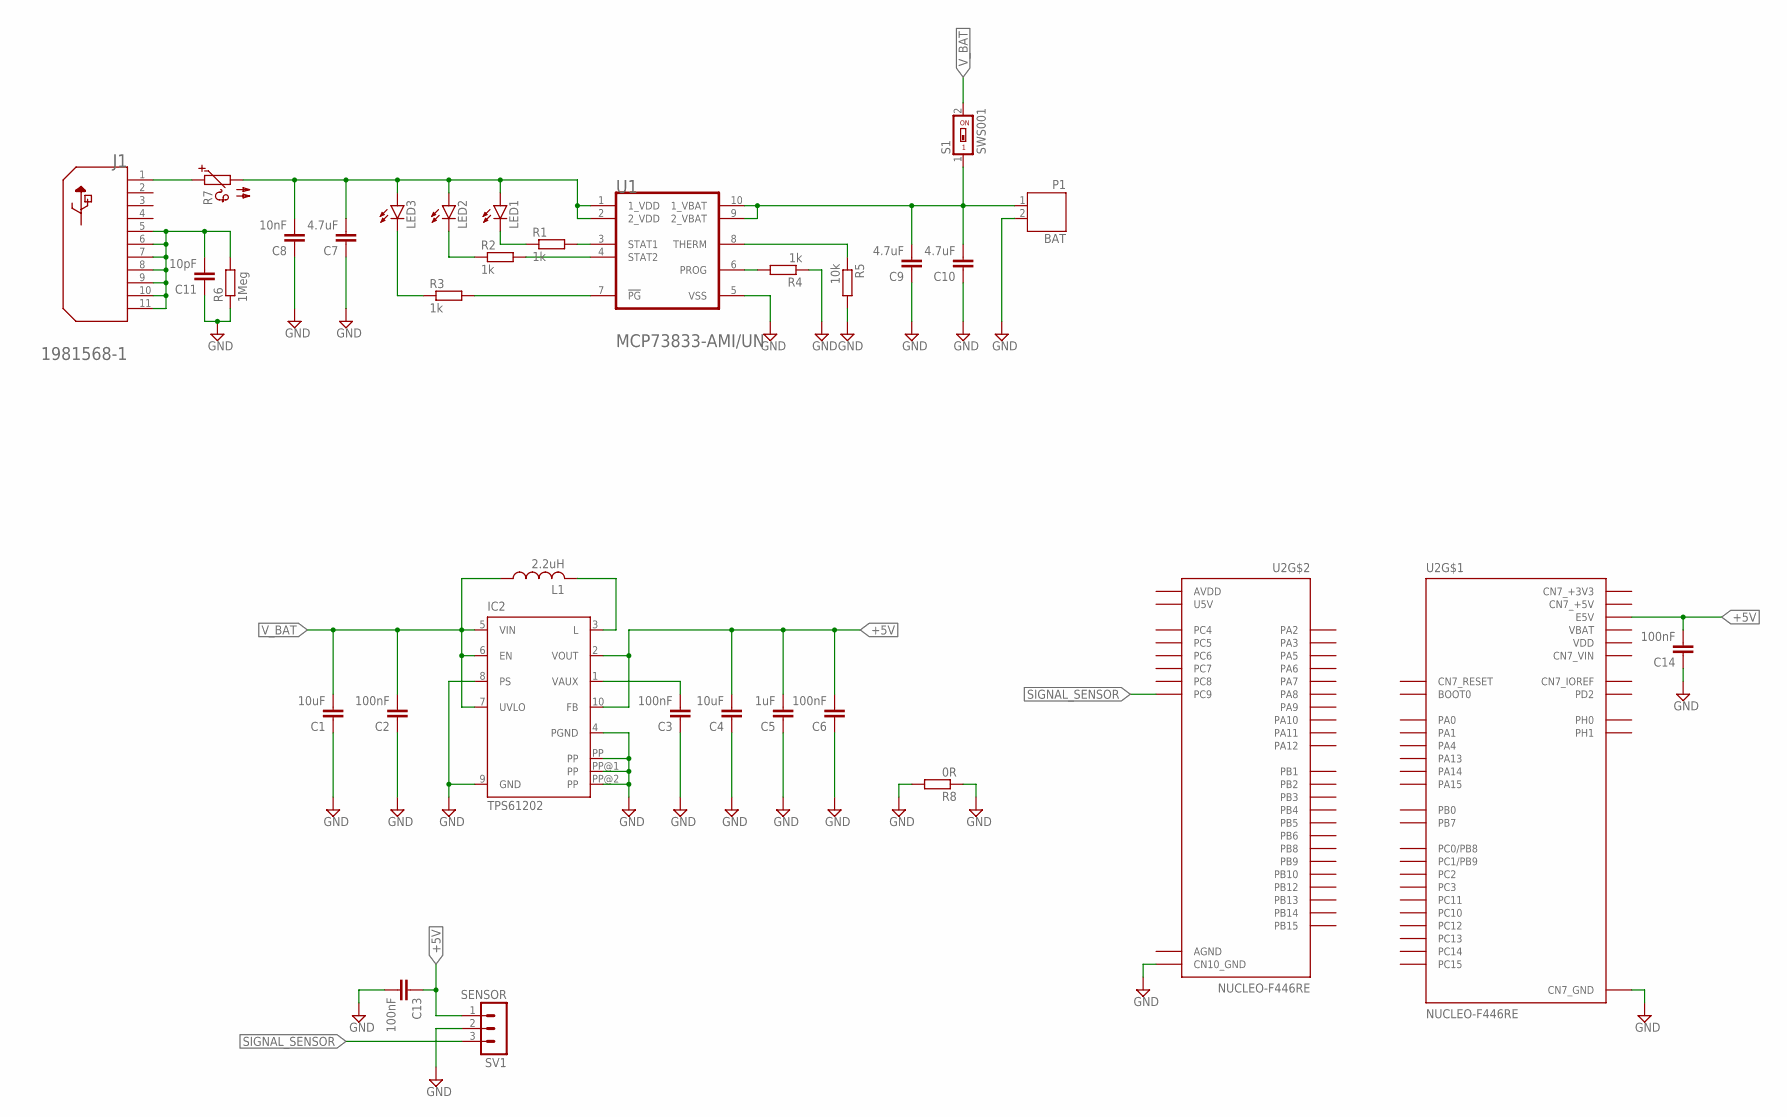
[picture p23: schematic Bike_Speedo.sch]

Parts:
C1, C4: 10uF; C0805
C2, C3, C6, C13, C14: 100nF; C0805
C5: 1uF; C0805
C7, C9, C10: 4.7uF; C0805
C8: 10nF; C0805
C11: 10pF; C0805
IC2: TPS61202; S-PDSO-N10
J1: TE_CONNECTIVITY_1981568-1TE_CONNECTIVITY_1981568-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; TE_CONNECTIVITY_1981568-1_0
L1: 2.2uH; L3216C
LED1, LED2, LED3: LEDSML0805; SML0805
P1: BAT; JST-PH2
R1, R2, R3, R4: 1k; R0805
R5: 10k; R0805
R6: 1Meg; R0805
R7: PTC660; P660
R8: 0R; R0805
S1: SWS001; SMS-001
SV1: SENSOR; MA03-1
U1: MICROCHIP_MCP73833-AMI-UNMICROCHIP_MCP73833-AMI-U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; MICROCHIP_MCP73833-AMI-UN_0
U2: NUCLEO-F446RE; MODULE_NUCLEO-F446RE

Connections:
+5V: C4.2, C5.2, C6.2, C13.1, C14.2, IC2.2 (VOUT), IC2.10 (FB), SV1.1, U2.CN7_6 (E5V)
AGND: U2.CN10_32 (AGND)
AREF: U2.CN5_8 (AREF)
AVDD: U2.CN10_7 (AVDD)
CN5_GND: U2.CN5_7 (CN5_GND)
CN6_+3V3: U2.CN6_4 (CN6_+3V3)
CN6_+5V: U2.CN6_5 (CN6_+5V)
CN6_GND: U2.CN6_6 (CN6_GND), U2.CN6_7 (CN6_GND)
CN6_VIN: U2.CN6_8 (CN6_VIN)
CN7_+3V3: U2.CN7_16 (CN7_+3V3)
CN7_+5V: U2.CN7_18 (CN7_+5V)
CN7_VIN: U2.CN7_24 (CN7_VIN)
GND: C1.1, C2.1, C3.1, C4.1, C5.1, C6.1, C7.1, C8.1, C9.1, C10.1, C11.1, C13.2, C14.1, IC2.4 (PGND), IC2.8 (PS), IC2.9 (GND), IC2.PP, IC2.PP@1 (PP), IC2.PP@2 (PP), P1.2, R4.1, R5.2, R6.1, R8.1, R8.2, SV1.2, U1.5 (VSS), U2.CN7_8 (CN7_GND), U2.CN7_19 (CN7_GND), U2.CN7_20 (CN7_GND), U2.CN7_22 (CN7_GND), U2.CN10_9 (CN10_GND), U2.CN10_20 (CN10_GND)
unnamed: J1.1 (VBUS), R7.1
unnamed: IC2.3 (L), L1.2
unnamed: C3.2, IC2.1 (VAUX)
unnamed: C7.2, C8.2, LED1.A, LED2.A, LED3.A, R7.2, U1.1 (1_VDD), U1.2 (2_VDD)
unnamed: C11.2, J1.5 (GND), J1.6 (SHLD1), J1.7 (SHLD2), J1.8 (SHLD3), J1.9 (SHLD4), J1.10 (SHLD5), J1.11 (SHLD6), R6.2
unnamed: LED1.C, R1.1
unnamed: LED2.C, R2.1
unnamed: LED3.C, R3.1
unnamed: R3.2, U1.7 (!PG!)
unnamed: R2.2, U1.4 (STAT2)
unnamed: R1.2, U1.3 (STAT1)
unnamed: R4.2, U1.6 (PROG)
unnamed: R5.1, U1.8 (THERM)
unnamed: C9.2, C10.2, P1.1, S1.1, U1.9 (2_VBAT), U1.10 (1_VBAT)
SIGNAL_SENSOR: SV1.3, U2.CN10_1 (PC9)
U5V: U2.CN10_8 (U5V)
VBAT: U2.CN7_33 (VBAT)
VDD: U2.CN7_5 (VDD)
V_BAT: C1.2, C2.2, IC2.5 (VIN), IC2.6 (EN), IC2.7 (UVLO), L1.1, S1.2

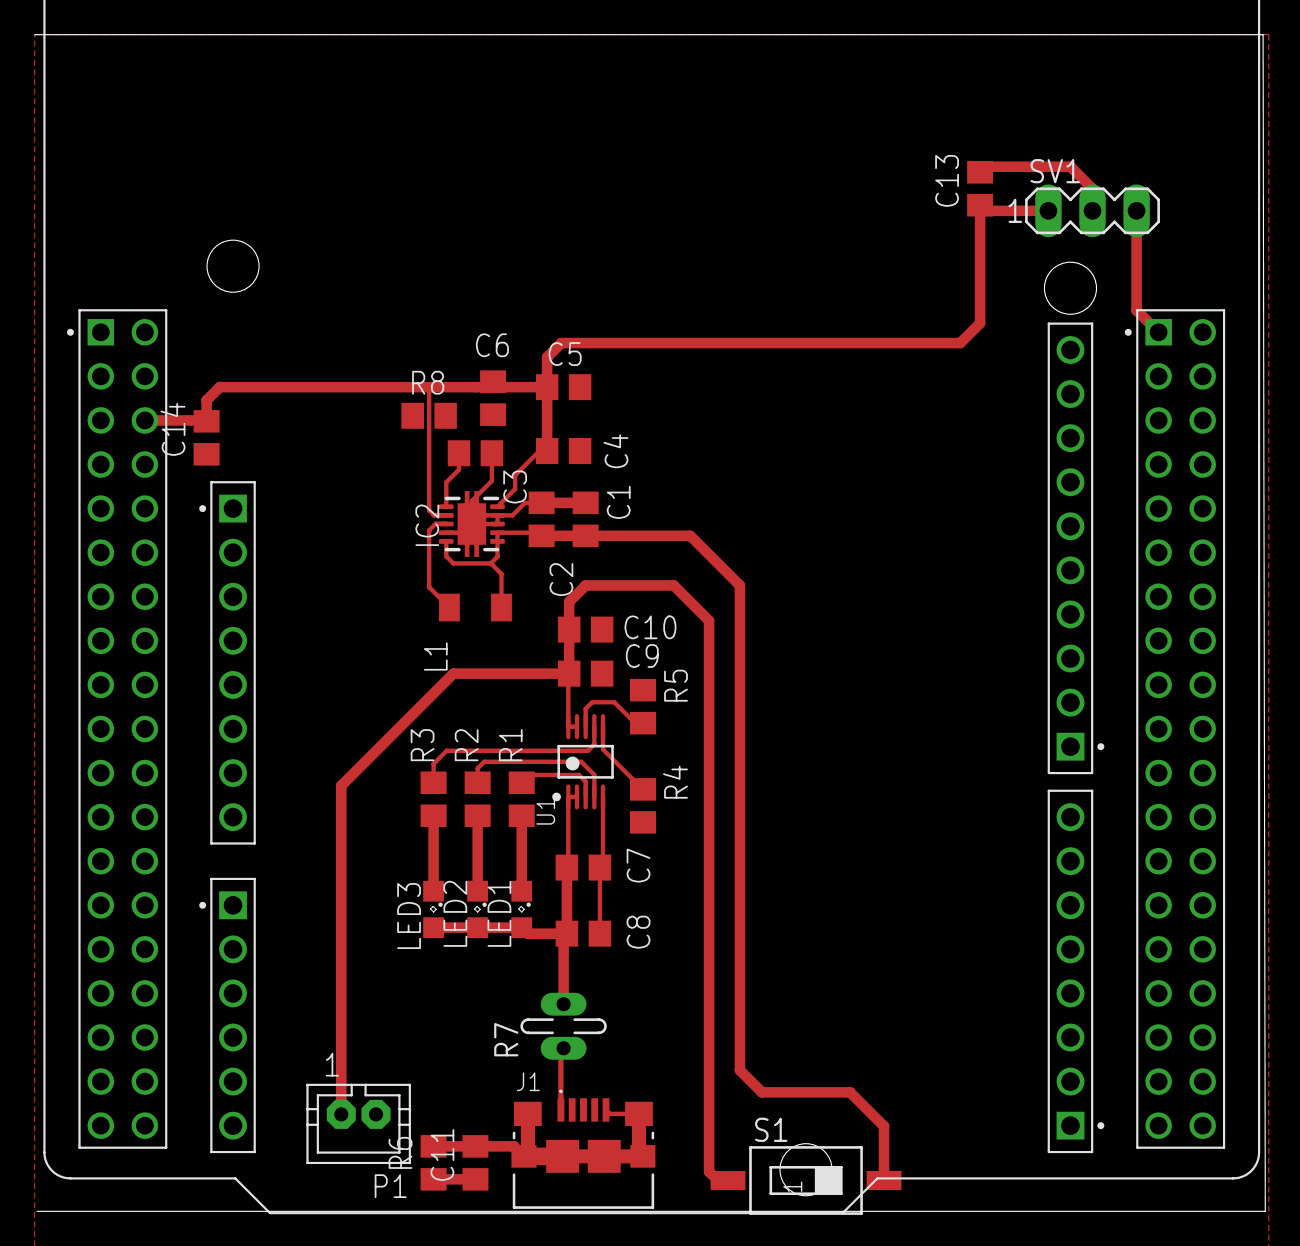
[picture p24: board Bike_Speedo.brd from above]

Board: 2 copper layers, 70.9 x 67.8 mm, 32 parts (0 on the bottom side), 19 nets.

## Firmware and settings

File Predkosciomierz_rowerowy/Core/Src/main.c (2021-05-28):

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
/* Includes ------------------------------------------------------------------*/
#include "main.h"
#include "spi.h"
#include "tim.h"
#include "usart.h"
#include "gpio.h"

#include "DEV_Config.h"
#include "LCD_Driver.h"
#include "LCD_GUI.h"
#include "LCD_Touch.h"
#include "BikeSpeedo.h"

/* USER CODE BEGIN Includes */
uint32_t IC_Value = 0;
/* USER CODE END Includes */


void SystemClock_Config(void);
/**
  * @brief  The application entry point.
  * @retval int
  */
int main(void)
{
  /* MCU Configuration--------------------------------------------------------*/

  /* Reset of all peripherals, Initializes the Flash interface and the Systick. */
  HAL_Init();

  /* Configure the system clock */
  SystemClock_Config();

  /* Initialize all configured peripherals */
  MX_GPIO_Init();
  MX_SPI1_Init();
  MX_TIM3_Init();
  MX_USART2_UART_Init();
  MX_TIM8_Init();
  MX_TIM6_Init();
  /* USER CODE BEGIN 2 */
	LCD_SCAN_DIR Lcd_ScanDir = SCAN_DIR_DFT;//SCAN_DIR_DFT = D2U_L2R	
	LCD_Init(Lcd_ScanDir, 1000);
	TP_Init(Lcd_ScanDir);
	
	TP_GetAdFac();
	init();
	
	HAL_TIM_IC_Start_IT(&htim8, TIM_CHANNEL_4);
  /* USER CODE END 2 */

  /* Infinite loop */
  while (1)
  {
		TP_Scan(0);
		if (sTP_DEV.chStatus & TP_PRESS_DOWN) // Update only when sth was touched
		{		
			processInput();
		}
  }
}

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
/* USER CODE BEGIN 4 */
void HAL_TIM_IC_CaptureCallback(TIM_HandleTypeDef *htim)
{
	if ((htim==&htim8)&&(htim->Channel == HAL_TIM_ACTIVE_CHANNEL_4))  // if interrput source is channel 3
	{
		IC_Value = HAL_TIM_ReadCapturedValue(&htim8, TIM_CHANNEL_4);
		IC_Value = IC_Value / 5;
		__HAL_TIM_SET_COUNTER(&htim8, 0);
	}
}

void HAL_TIM_PeriodElapsedCallback(TIM_HandleTypeDef *htim)
{
	if(htim->Instance == TIM6)
	{
		updateVelocityValue(IC_Value);
		
		if (__HAL_TIM_GET_COUNTER(&htim8) > 25000) //5s
			IC_Value = 0;
	}
}

/* USER CODE END 4 */
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


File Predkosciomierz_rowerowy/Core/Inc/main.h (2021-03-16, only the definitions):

#define B1_Pin GPIO_PIN_13
#define B1_GPIO_Port GPIOC
#define USART_TX_Pin GPIO_PIN_2
#define USART_TX_GPIO_Port GPIOA
#define USART_RX_Pin GPIO_PIN_3
#define USART_RX_GPIO_Port GPIOA
#define TP_BUSY_Pin GPIO_PIN_10
#define TP_BUSY_GPIO_Port GPIOB
#define LCD_DC_Pin GPIO_PIN_8
#define LCD_DC_GPIO_Port GPIOA
#define LCD_RST_Pin GPIO_PIN_9
#define LCD_RST_GPIO_Port GPIOA
#define TMS_Pin GPIO_PIN_13
#define TMS_GPIO_Port GPIOA
#define TCK_Pin GPIO_PIN_14
#define TCK_GPIO_Port GPIOA
#define TP_IRQ_Pin GPIO_PIN_3
#define TP_IRQ_GPIO_Port GPIOB
#define SD_CS_Pin GPIO_PIN_4
#define SD_CS_GPIO_Port GPIOB
#define TP_CS_Pin GPIO_PIN_5
#define TP_CS_GPIO_Port GPIOB
#define LCD_CS_Pin GPIO_PIN_6
#define LCD_CS_GPIO_Port GPIOB

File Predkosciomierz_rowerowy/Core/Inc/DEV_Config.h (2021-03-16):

/*****************************************************************************
* | File      	:	DEV_Config.c
* | Author      :   Waveshare team
* | Function    :	Show SDcard BMP picto LCD 
* | Info        :
*   Provide the hardware underlying interface	 
*----------------
* |	This version:   V1.0
* | Date        :   2018-01-11
* | Info        :   Basic version
*
******************************************************************************/
#ifndef _DEV_CONFIG_H_
#define _DEV_CONFIG_H_

#include "stm32f4xx_hal.h"
#include "main.h"

#define USE_SPI_4W 1
#define USE_IIC 0

//SPI
#define SPI1_CLK_0		HAL_GPIO_WritePin(SPI1_SCK_GPIO_Port, SPI1_SCK_Pin, GPIO_PIN_RESET)
#define SPI1_CLK_1		HAL_GPIO_WritePin(SPI1_SCK_GPIO_Port, SPI1_SCK_Pin, GPIO_PIN_SET)

#define GET_SPI1_MISO   HAL_GPIO_ReadPin(SPI1_MISO_GPIO_Port, SPI1_MISO_Pin)

#define SPI1_MOSI_0		HAL_GPIO_WritePin(SPI1_MOSI_GPIO_Port, SPI1_MOSI_Pin, GPIO_PIN_RESET)
#define SPI1_MOSI_1		HAL_GPIO_WritePin(SPI1_MOSI_GPIO_Port, SPI1_MOSI_Pin, GPIO_PIN_SET)

//LCD
#define LCD_CS_0		HAL_GPIO_WritePin(LCD_CS_GPIO_Port, LCD_CS_Pin, GPIO_PIN_RESET)
#define LCD_CS_1		HAL_GPIO_WritePin(LCD_CS_GPIO_Port, LCD_CS_Pin, GPIO_PIN_SET)

#define LCD_RST_0		HAL_GPIO_WritePin(LCD_RST_GPIO_Port, LCD_RST_Pin, GPIO_PIN_RESET)
#define LCD_RST_1		HAL_GPIO_WritePin(LCD_RST_GPIO_Port, LCD_RST_Pin, GPIO_PIN_SET)

#define LCD_DC_0		HAL_GPIO_WritePin(LCD_DC_GPIO_Port, LCD_DC_Pin, GPIO_PIN_RESET)
#define LCD_DC_1		HAL_GPIO_WritePin(LCD_DC_GPIO_Port, LCD_DC_Pin, GPIO_PIN_SET)

//Touch
#define TP_CS_0			HAL_GPIO_WritePin(TP_CS_GPIO_Port, TP_CS_Pin, GPIO_PIN_RESET)
#define TP_CS_1			HAL_GPIO_WritePin(TP_CS_GPIO_Port, TP_CS_Pin, GPIO_PIN_SET)

#define GET_TP_BUSY		HAL_GPIO_ReadPin(TP_BUSY_GPIO_Port, TP_BUSY_Pin)

#define GET_TP_IRQ		HAL_GPIO_ReadPin(TP_IRQ_GPIO_Port, TP_IRQ_Pin)

//SD card 
#define  MAX_BMP_FILES  25 	
#define SD_CS_0			HAL_GPIO_WritePin(SD_CS_GPIO_Port, SD_CS_Pin, GPIO_PIN_RESET)
#define SD_CS_1			HAL_GPIO_WritePin(SD_CS_GPIO_Port, SD_CS_Pin, GPIO_PIN_SET)

/*------------------------------------------------------------------------------------------------------*/
void System_Exit(void);
void PWM_SetValue(uint16_t value);
uint8_t SPI4W_Write_Byte(uint8_t value);
uint8_t SPI4W_Read_Byte(uint8_t value);

void Driver_Delay_ms(uint32_t xms);
void Driver_Delay_us(uint32_t xus);

#endif

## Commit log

2021-03-17 Add cod for sensor
2021-03-22 Add prototype schematic
    [Bike_Speedo.sch]
2021-04-12 Update schematic
    [Bike_Speedo.sch]
2021-05-11 fixed crazy velocities
2021-05-12 update PCB
    [Bike_Speedo.brd, Bike_Speedo.sch]
2021-05-13 modified PCB
    [Bike_Speedo.brd, Bike_Speedo.sch]
2021-06-01 Update schematic and board
    [Bike_Speedo.brd, Bike_Speedo.sch]

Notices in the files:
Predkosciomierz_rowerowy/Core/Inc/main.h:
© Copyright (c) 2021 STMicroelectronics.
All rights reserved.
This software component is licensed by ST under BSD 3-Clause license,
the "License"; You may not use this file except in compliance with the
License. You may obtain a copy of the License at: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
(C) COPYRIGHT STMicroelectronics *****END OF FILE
